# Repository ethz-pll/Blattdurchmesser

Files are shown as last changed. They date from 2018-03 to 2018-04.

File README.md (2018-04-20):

<!--
docu: [![doxygen html](https://raw.githubusercontent.com/ethz-pll/Blattdurchmesser/result/docu/doc/html/doxygen.png)](https://rawgit.com/ethz-pll/Blattdurchmesser/result/docu/doc/html/index.html)

[comment]: # (doxygen latex pdf output? https://github.com/drtrigon/sketchbook/blob/result/docu/doc/latex/refman.pdf)

code: [![Build Status](https://travis-ci.org/ethz-pll/Blattdurchmesser.svg?branch=master)](https://travis-ci.org/ethz-pll/Blattdurchmesser)

PCB: [![design rule check status](https://edrc.me/api/v1/user/drtrigon/project/ethz-pll-eagle/img/status.svg)](https://edrc.me/g/drtrigon/ethz-pll-eagle)
[![GERBER Build Status](https://travis-ci.org/drtrigon/ethz-pll-eagle.svg?branch=master)](https://travis-ci.org/drtrigon/ethz-pll-eagle)
https://gitlab.ethz.ch/PLL/eagle

[![projects/Blattdurchmesser/Blattdurchmesser_sch.png](https://raw.githubusercontent.com/drtrigon/ethz-pll-eagle/result/pcb/projects/Blattdurchmesser/Blattdurchmesser_sch.png)](https://github.com/drtrigon/ethz-pll-eagle/blob/result/pcb/projects/Blattdurchmesser/Blattdurchmesser_sch.png)

[![projects/Blattdurchmesser/Blattdurchmesser.brd from EDRC.me](https://edrc.me/api/v1/user/drtrigon/project/ethz-pll-eagle/img/file/projects%2FBlattdurchmesser%2FBlattdurchmesser.png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)](https://edrc.me/g/drtrigon/ethz-pll-eagle)
[![projects/Blattdurchmesser/Blattdurchmesser.png](https://raw.githubusercontent.com/drtrigon/ethz-pll-eagle/result/pcb/projects/Blattdurchmesser/Blattdurchmesser.png)](https://github.com/drtrigon/ethz-pll-eagle/blob/result/pcb/projects/Blattdurchmesser/Blattdurchmesser.png)
* GERBER: https://github.com/drtrigon/ethz-pll-eagle/blob/result/pcb/projects/Blattdurchmesser/Blattdurchmesser.zip
* partlist: https://github.com/drtrigon/ethz-pll-eagle/blob/result/pcb/projects/Blattdurchmesser/Blattdurchmesser.txt

https://github.com/drtrigon/ethz-pll-eagle/tree/result/pcb/projects/Blattdurchmesser logs:
* https://github.com/drtrigon/ethz-pll-eagle/blob/result/pcb/projects/Blattdurchmesser/Blattdurchmesser.gpi
* https://github.com/drtrigon/ethz-pll-eagle/blob/result/pcb/projects/Blattdurchmesser/Blattdurchmesser.dri

[![projects/Blattdurchmesser/Blattdurchmesser_auto.png](https://raw.githubusercontent.com/drtrigon/ethz-pll-eagle/result/pcb/projects/Blattdurchmesser/Blattdurchmesser_auto.png)](https://github.com/drtrigon/ethz-pll-eagle/blob/result/pcb/projects/Blattdurchmesser/Blattdurchmesser_auto.png)
-->
docu: doxygen html[...](https://rawgit.com/ethz-pll/Blattdurchmesser/result/docu/doc/html/index.html)

[comment]: # (doxygen latex pdf output? https://github.com/drtrigon/sketchbook/blob/result/docu/doc/latex/refman.pdf)

code: [...](https://travis-ci.org/ethz-pll/Blattdurchmesser)

PCB: design rule check status[...](https://edrc.me/g/drtrigon/ethz-pll-eagle)
[...](https://travis-ci.org/drtrigon/ethz-pll-eagle)
https://gitlab.ethz.ch/PLL/eagle


[...](https://github.com/drtrigon/ethz-pll-eagle/blob/result/pcb/projects/Blattdurchmesser/Blattdurchmesser_sch.png)

projects/Blattdurchmesser/Blattdurchmesser.brd from EDRC.me[...](https://edrc.me/g/drtrigon/ethz-pll-eagle)

[...](https://github.com/drtrigon/ethz-pll-eagle/blob/result/pcb/projects/Blattdurchmesser/Blattdurchmesser.png)
* GERBER: https://github.com/drtrigon/ethz-pll-eagle/blob/result/pcb/projects/Blattdurchmesser/Blattdurchmesser.zip
* partlist: https://github.com/drtrigon/ethz-pll-eagle/blob/result/pcb/projects/Blattdurchmesser/Blattdurchmesser.txt

https://github.com/drtrigon/ethz-pll-eagle/tree/result/pcb/projects/Blattdurchmesser logs:
* https://github.com/drtrigon/ethz-pll-eagle/blob/result/pcb/projects/Blattdurchmesser/Blattdurchmesser.gpi
* https://github.com/drtrigon/ethz-pll-eagle/blob/result/pcb/projects/Blattdurchmesser/Blattdurchmesser.dri


[...](https://github.com/drtrigon/ethz-pll-eagle/blob/result/pcb/projects/Blattdurchmesser/Blattdurchmesser_auto.png)

CAD: 
* https://gitlab.ethz.ch/PLL/Blattdurchmesser/blob/master/Catia/40%20mm%20Aluprofil%20v13.stl
  ([github](https://github.com/ethz-pll/Blattdurchmesser/blob/master/Catia/40%20mm%20Aluprofil%20v13.stl))
* https://gitlab.ethz.ch/PLL/Blattdurchmesser/blob/master/Catia/Saegeblatt_Anschlag.stl
  ([github](https://github.com/ethz-pll/Blattdurchmesser/blob/master/Catia/Saegeblatt_Anschlag.stl))
* https://gitlab.ethz.ch/PLL/Blattdurchmesser/blob/master/Catia/Saegeblatt_Endplatte.stl
  ([github](https://github.com/ethz-pll/Blattdurchmesser/blob/master/Catia/Saegeblatt_Endplatte.stl))
* https://gitlab.ethz.ch/PLL/Blattdurchmesser/blob/master/Catia/Saegeblatt_Schlitten.stl
  ([github](https://github.com/ethz-pll/Blattdurchmesser/blob/master/Catia/Saegeblatt_Schlitten.stl))

partlist: https://rawgit.com/ethz-pll/Blattdurchmesser/master/Materialliste.htm

[comment]: # (@htmlonly
    <table>
      <tr>
        <td>
          <script src="https://embed.github.com/view/3d/ethz-pll/Blattdurchmesser/master/Catia/40%20mm%20Aluprofil%20v13.stl"></script><br>
          <script src="https://embed.github.com/view/3d/ethz-pll/Blattdurchmesser/master/Catia/Saegeblatt_Anschlag.stl"></script><br>
          <script src="https://embed.github.com/view/3d/ethz-pll/Blattdurchmesser/master/Catia/Saegeblatt_Endplatte.stl"></script><br>
          <script src="https://embed.github.com/view/3d/ethz-pll/Blattdurchmesser/master/Catia/Saegeblatt_Schlitten.stl"></script><br>
        </td>
      </tr>
    </table>
@endhtmlonly)

#### changelog pcb (eagle)

todo 1.0 -> 1.1

* ...

main changes 1.0 -> 1.1

* ...

## Setup

I would like to use features like CI (continous integration) keep a copy/mirror on e.g. github and more.

ETHZ GitLab could (and may be already does) support such features but I do not understand how this works.

Maintaining a copy/mirror (more precise: with 2 remotes overloaded origin) on GitHub also allows
to use GitLab and GitHub together and by that all the nice featurs on GitHub.
See also; https://steveperkins.com/migrating-projects-from-github-to-gitlab/

"Option 2: Overload Origin with Both Remotes (needs one single pull/push only)"; in order to clone
and set this repo up use:
```
$ git clone https://gitlab.ethz.ch/PLL/Blattdurchmesser.git
$ cd Blattdurchmesser
$ git remote set-url --add origin https://github.com/ethz-pll/Blattdurchmesser.git
```
you can check the settings with:
```
$ git remote -v
origin  https://gitlab.ethz.ch/PLL/Blattdurchmesser.git (fetch)
origin  https://gitlab.ethz.ch/PLL/Blattdurchmesser.git (push)
origin  https://github.com/ethz-pll/Blattdurchmesser.git (push)
```

### Enable Travis CI for a Repository (for Arduino)
https://learn.adafruit.com/continuous-integration-arduino-and-you/testing-your-project

Login to Travis-CI using the GitHub account and enable Travis-CI for the given repo.

Add a .travis.yml file to your project, commit, pull/push and enjoy.

### Enable EDRC.ME for a Repository (for Eagle)
See https://gitlab.ethz.ch/PLL/eagle

### Enable CAD View (for Catia)
* https://help.github.com/articles/3d-file-viewer/
* https://blog.github.com/2013-04-09-stl-file-viewing/
* https://blog.github.com/2013-09-17-3d-file-diffs/

#### Create CAD (.stl) Designs online easily
See https://www.tinkercad.com/

### Further Info
* convert STEP file to .stl online: https://www.makexyz.com/convert/step-to-stl
* convert Catia file to .stl online: https://www.convertcadfiles.com/de/konvertieren/
* add doxygen to repository
  * The Well-Automated Arduino Library - Adafruit Learning System: https://learn.adafruit.com/the-well-automated-arduino-library/doxygen
  * https://stackoverflow.com/questions/35500277/doxygen-for-ino-files-arduino

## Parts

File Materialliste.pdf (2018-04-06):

Bezeichnung | Laden | Art.-Nr. | Preis | Anzahl
Original Arduino Uno R3 (Atmega328) *RETAIL* | www.play-zone.ch | | 28.90 | 1
A4988 Stepper Driver Modul | www.play-zone.ch | 8.90 | 1 bei www.distrelec.ch CHF 30.35 / bei www.3dware.ch CHF 4.20
OLED Modul 128 x 64 Pixel, I2C, Weiss, 0.96 inch, SSD1306 | www.play-zone.ch | | 14.90 | 1 | welcher? SSD1306 oder …
OLED Modul 1.3" / 128 x 64 Pixel, I2C, Weiss, SH1106 | www.play-zone.ch | | 18.90 | 1 | … SH1106? welchen habe ich hier? Siehe auch https://forum.arduino.cc/index.php?topic=256374.0
Stepper Motor, 200 step, DC 8.64V, 0.24A | FIRST-Lab | (ca. 25.00) | 1 Betrieben mit 12V (mehr Drehmoment, weniger blockieren) - Kühlung??
Profil-System (Item, Kanya, etc.) Profil 40 x 40 x 100 mm | FIRST-Lab | 1 Was für System haben wir verwendet?
Verbindung Stepper Motor zu Profil-System, blau, H.J. Rusterholz | FIRST-Lab | 3D-Druck | | 1
Spindel M5 x 100mm, 0.8mm/Umdrehung | FIRST-Lab | | | 1
Bronze-Buchse M5 | FIRST-Lab | | | 1
Leuchtenklemmen, 6mm2 | lager.phys.ethz.ch | 30067.6 | 1.79 | 1 | welche Kupplung?
Stellringe, 3, 7, M2 | lager.phys.ethz.ch | 20247.2 | 0.43 | 2 | welche Kupplung?
PVC-Schläuche, 2, 4 | lager.phys.ethz.ch | 40001.1 | 0.37 | 15 mm | welche Kupplung?
Kühlkörper, Typ FK 214/SA CB, 15 K/W | lager.phys.ethz.ch | 30049.4 | 0.64 | 3
Kupplungen/Klaue/Nabenklemmung mit Passfedernut: https://de.misumi-ec.com/vona2/detail/110300125940/ | welche Kupplung?
Wellenkupplung: http://forums.reprap.org/read.php?246,280197
Kardan: https://de.aliexpress.com/item/5pcs-Cross-universal-joint-drive-shaft-axle-coupling-metal-connector-diy-toy-accessories-technology-model-parts/32827812832.html Drehstarre Kupplung: http://shop.myhobby-cnc.de/bauteile/mechanische-bauteile/kleinteile/21/drehstarre-kupplung
ROTEX Kupplung KTR Rotex 28: http://www.maschinenteil24.de/Mechanik/Mechanische-Baugruppen/Kupplungen/Kupplung-KTR-Rotex-28.html
Kardan: https://de.aliexpress.com/item/5pcs-Cross-universal-joint-drive-shaft-axle-coupling-metal-connector-diy-toy-accessories-technology-model-parts/32827812832.html Starre Kupplungen: http://www.directindustry.de/industrie-hersteller/starre-kupplung-61105.html
Vermeidung von Kupplungsausfällen: http://deutsch.ruland.com/a_articles_avoid_coup_failure_de.asp
Gabellichtschranke, PM-T64, Panasonic | www.distrelec.ch | 300-38-924 | 18.36 | 1
Konfektioniertes Kabel, 2 m, 3.7 mm, 0.2 mm² 4-Core, CN-14A-C2, Panasonic | www.distrelec.ch | 300-38-891 | 8.37 | 1
Relais, TX2-5V, Panasonic | www.distrelec.ch | 137-10-935 | 3.51 | 1
Miniatur-Mikroschalter, mit Hebel | lager.phys.ethz.ch | 30167.2 | 8.74
Schlitten PTFE: "Catia\Saegeblatt_Schlitten.pdf" | (Lehr-)Werkstatt | | | 1
Anschlag Al: "Catia\Saegeblatt_Anschlag.pdf" | (Lehr-)Werkstatt | | | 1 | besser SS? wegen Verschleiss…?
Endplatte Al: "Catia\Saegeblatt_Endplatte.pdf" | (Lehr-)Werkstatt | | | 1

Kostenstelle ist 2205, Vermerk "Wafersäge"

bei www.distrelec.ch CHF 30.35 / bei www.3dware.ch CHF 4.20
welcher? SSD1306 oder …
… SH1106? welchen habe ich hier? Siehe auch https://forum.arduino.cc/index.php?topic=256374.0

Betrieben mit 12V (mehr Drehmoment, weniger blockieren) - Kühlung??
Was für System haben wir verwendet?

welche Kupplung?
welche Kupplung?
welche Kupplung?

welche Kupplung?

besser SS? wegen Verschleiss…?

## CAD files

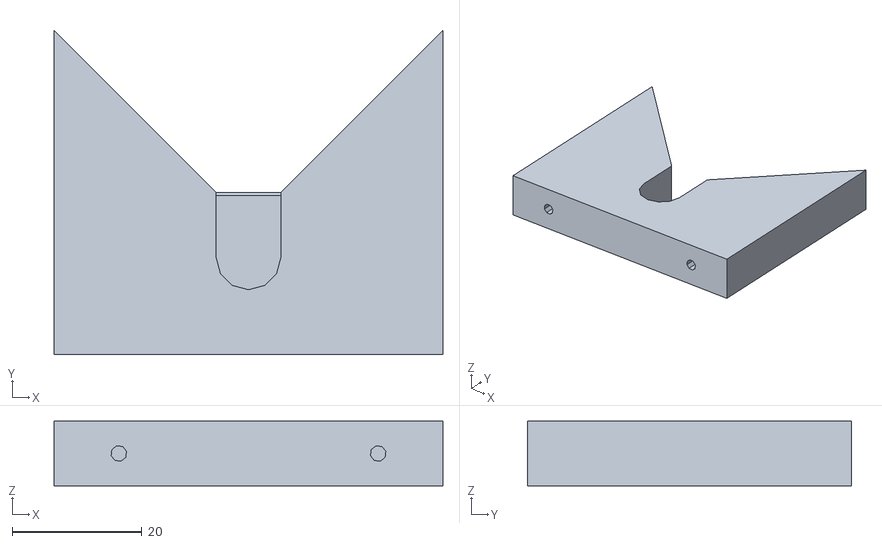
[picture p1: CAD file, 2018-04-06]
Catia/Saegeblatt_Anschlag.stl
60.0 x 50.0 x 10.0

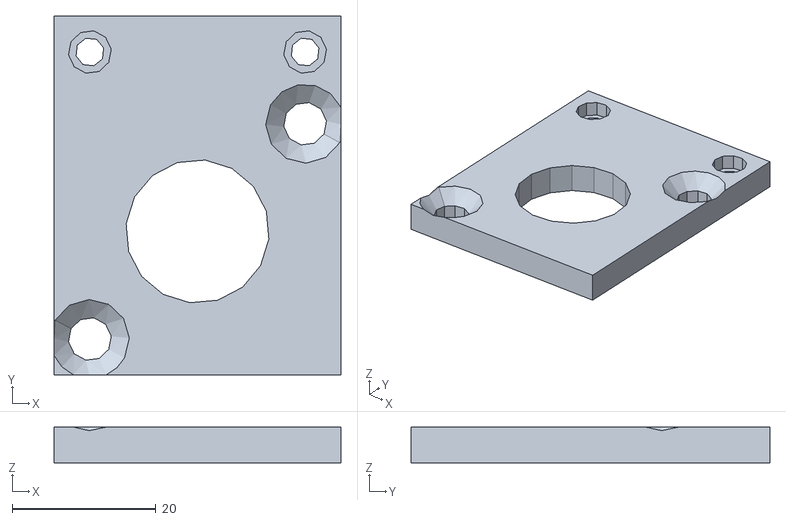
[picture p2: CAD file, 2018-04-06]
Catia/Saegeblatt_Endplatte.stl
40.0 x 50.0 x 5.00

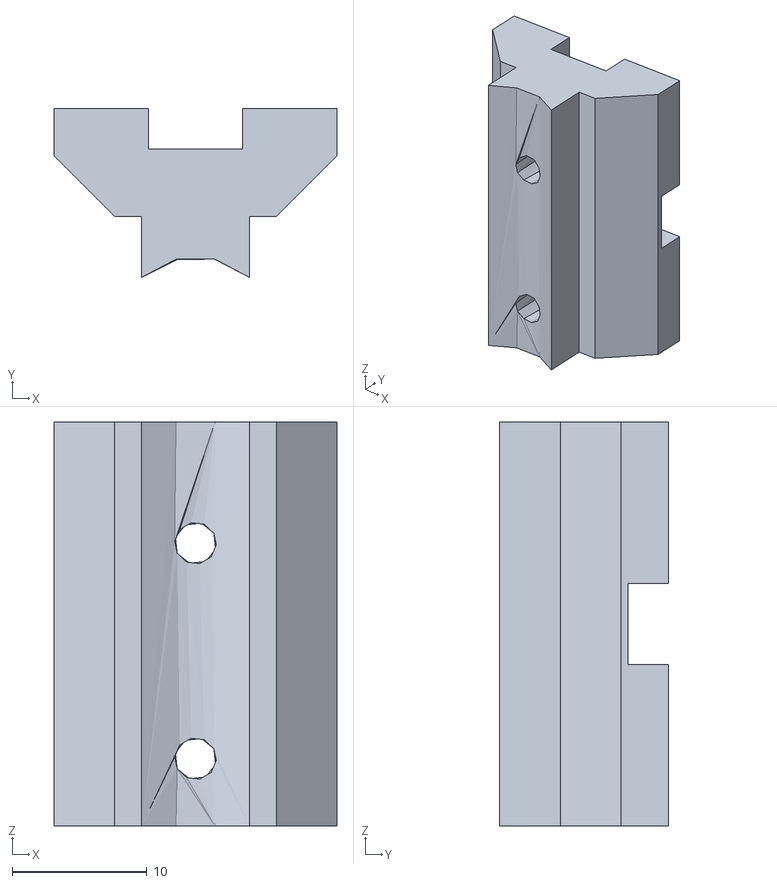
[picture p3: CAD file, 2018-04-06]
Catia/Saegeblatt_Schlitten.stl
21.0 x 12.5 x 30.0

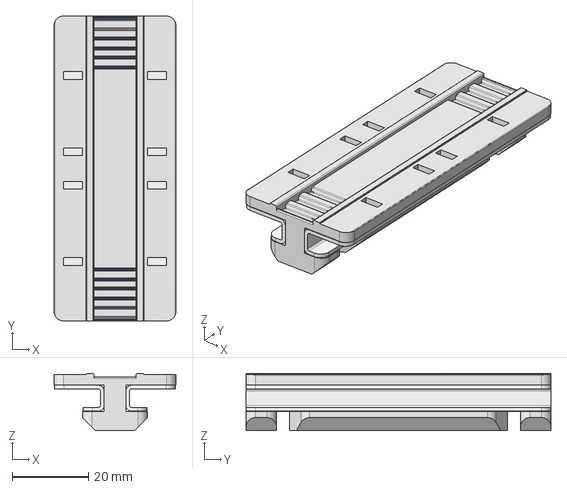
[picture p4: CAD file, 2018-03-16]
Catia/item_0060739_Gleitschlitten_F_hrung_8_80x40_4.stp
32.0 x 80.0 x 15.0 mm

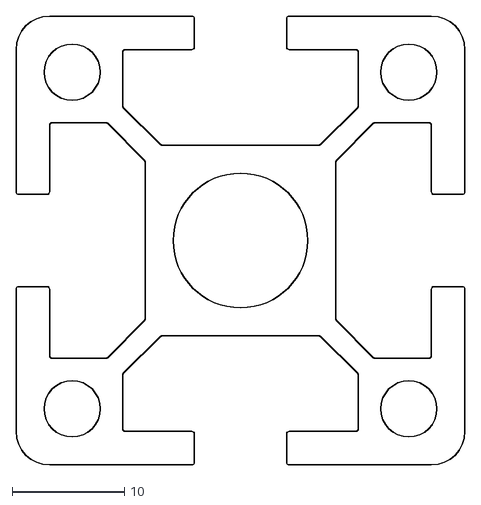
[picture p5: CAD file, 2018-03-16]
Catia/40mm Aluprofil.dxf
40.0 x 40.0

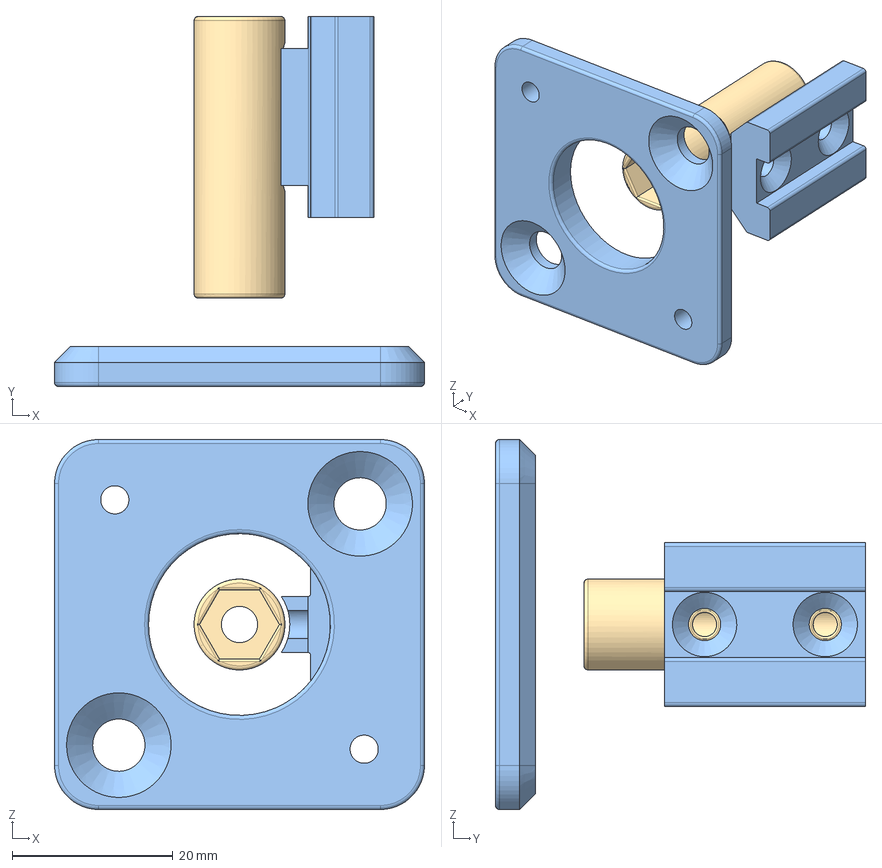
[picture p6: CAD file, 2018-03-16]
Catia/40 mm Aluprofil v13.step
46.0 x 46.0 x 46.0 mm

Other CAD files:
Catia/40 mm Aluprofil v13.f3d
Catia/40 mm Aluprofil v13.iges
Catia/40 mm Aluprofil v13.stl
Catia/Saegeblatt_Anschlag.CATPart
Catia/Saegeblatt_Endplatte.CATPart
Catia/Saegeblatt_Schlitten.CATPart

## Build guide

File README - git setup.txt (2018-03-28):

I would like to use features like CI (continous integration) keep a copy/mirror on e.g. github and more.

ETHZ GitLab could (and may be already does) support such features but I do not understand how this works.

Maintaining a copy/mirror (more precise: with 2 remotes overloaded origin) on GitHub also allows
to use GitLab and GitHub together and by that all the nice featurs on GitHub.
https://steveperkins.com/migrating-projects-from-github-to-gitlab/

Option 2: Overload Origin with Both Remotes (needs one single pull/push only);
$ git remote set-url --add origin https://github.com/drtrigon/ethz-pll-Blattdurchmesser.git

https://gitlab.ethz.ch/PLL/Blattdurchmesser
https://github.com/drtrigon/ethz-pll-Blattdurchmesser

Enable Travis CI for a Repository (for Arduino)
https://learn.adafruit.com/continuous-integration-arduino-and-you/testing-your-project

Login to Travis-CI using the GitHub account and enable Travis-CI for the given repo.

Add a .travis.yml file to your project, commit, pull/push and enjoy.

This travis file supports Arduino IDE 1.6.5 only we use 1.8.2.

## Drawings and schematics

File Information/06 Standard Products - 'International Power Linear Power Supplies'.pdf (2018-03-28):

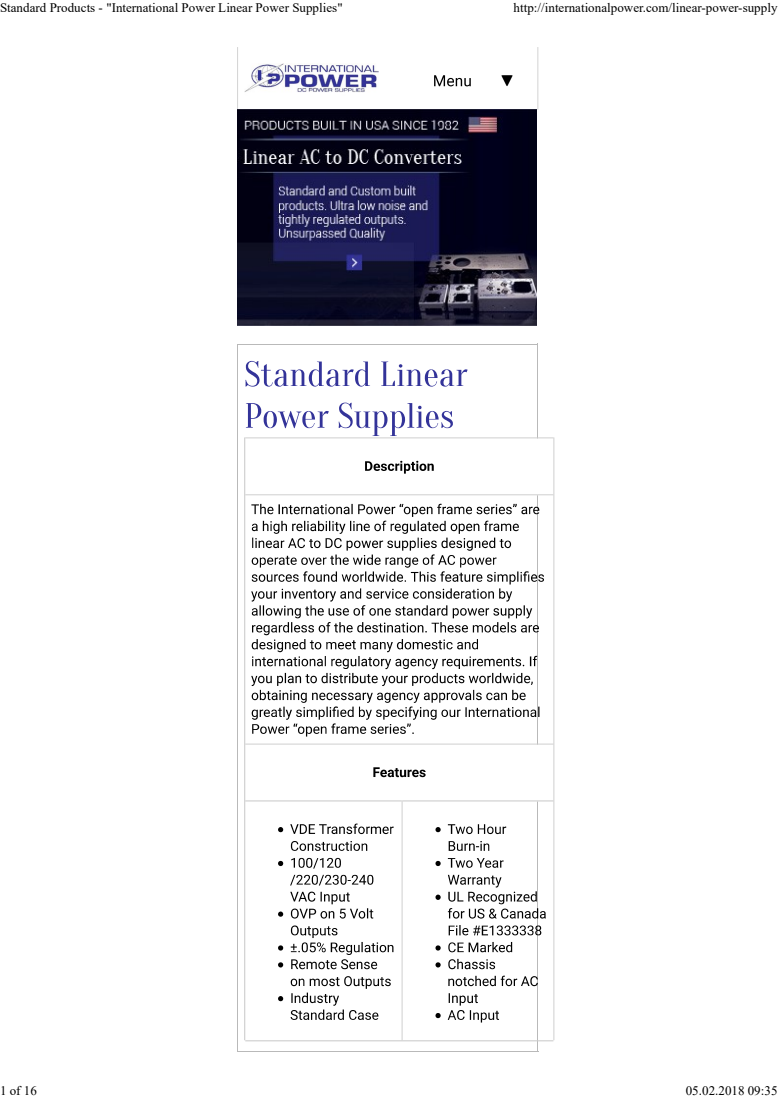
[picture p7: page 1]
Standard Products - "International Power Linear Power Supplies"; http://internationalpower.com/linear-power-supply

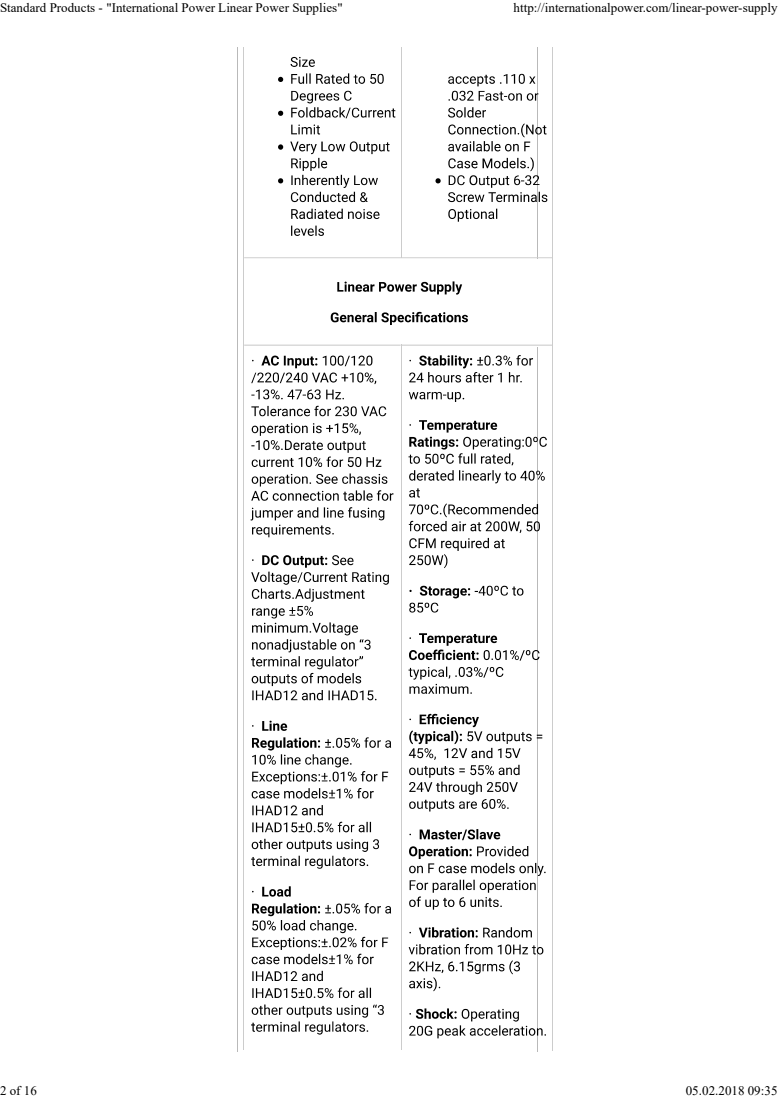
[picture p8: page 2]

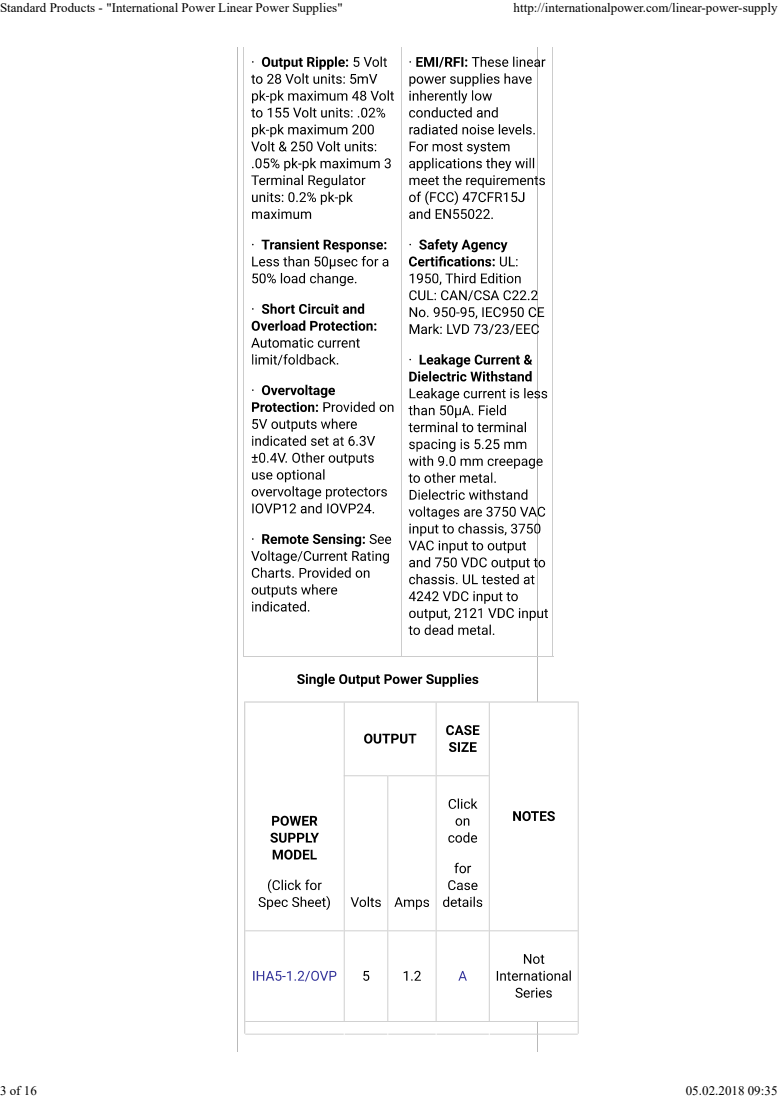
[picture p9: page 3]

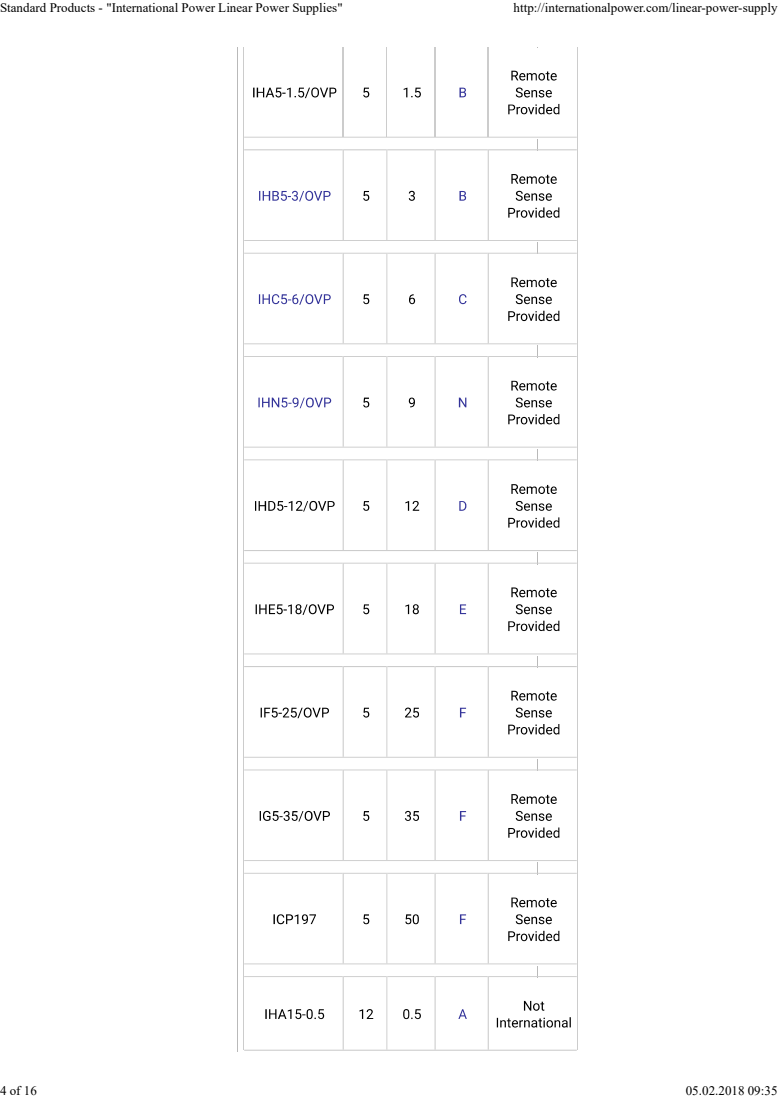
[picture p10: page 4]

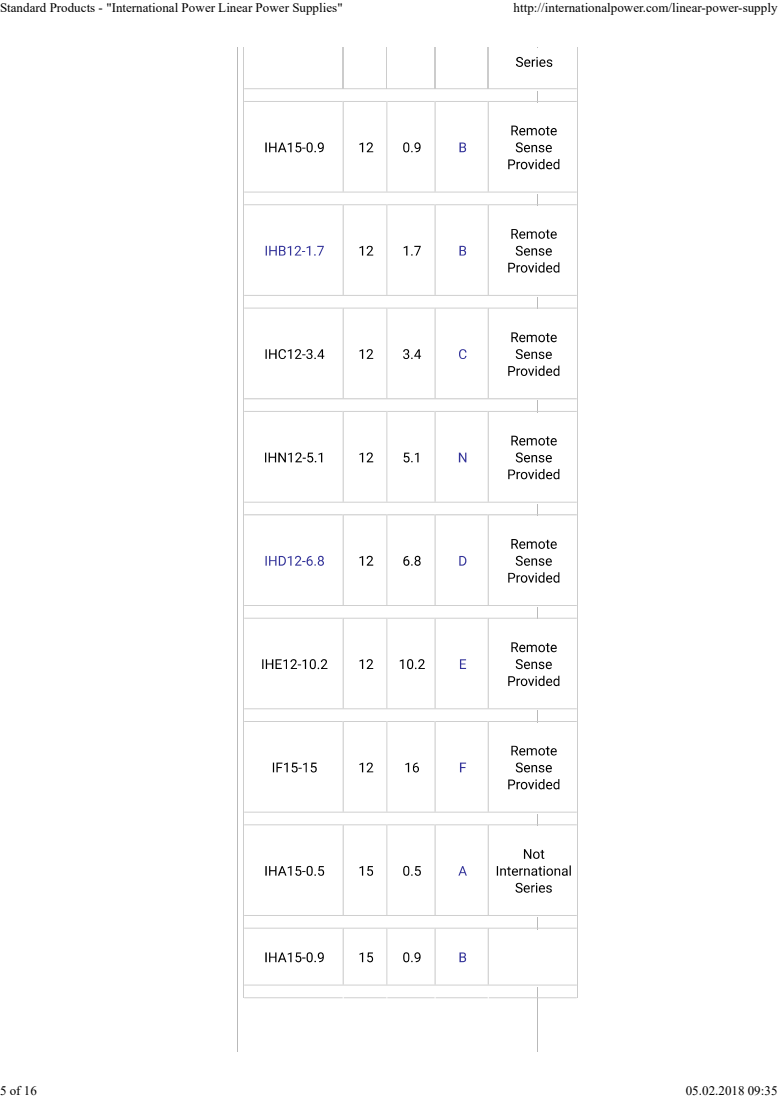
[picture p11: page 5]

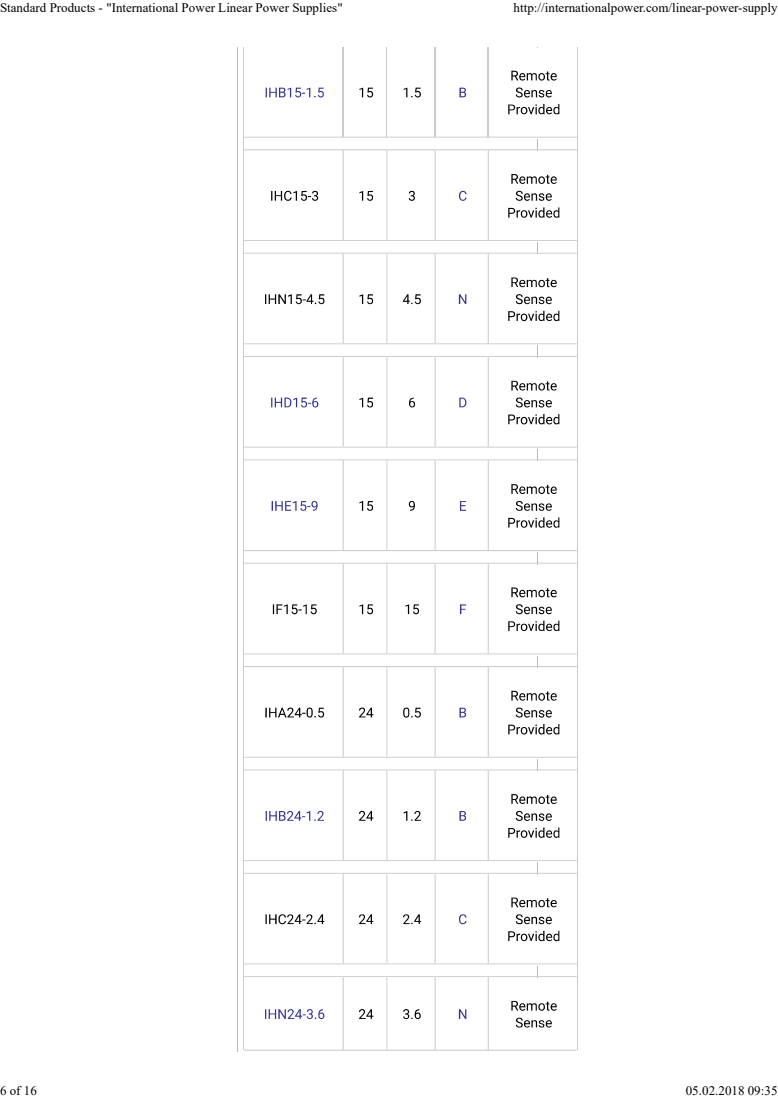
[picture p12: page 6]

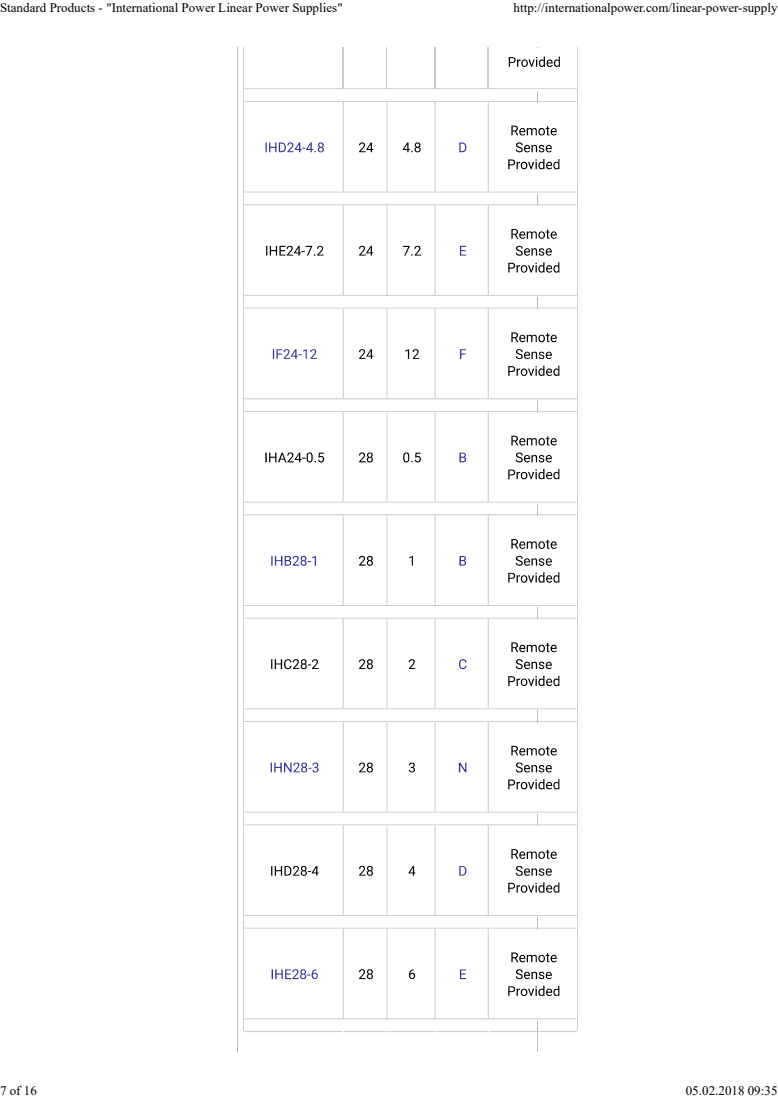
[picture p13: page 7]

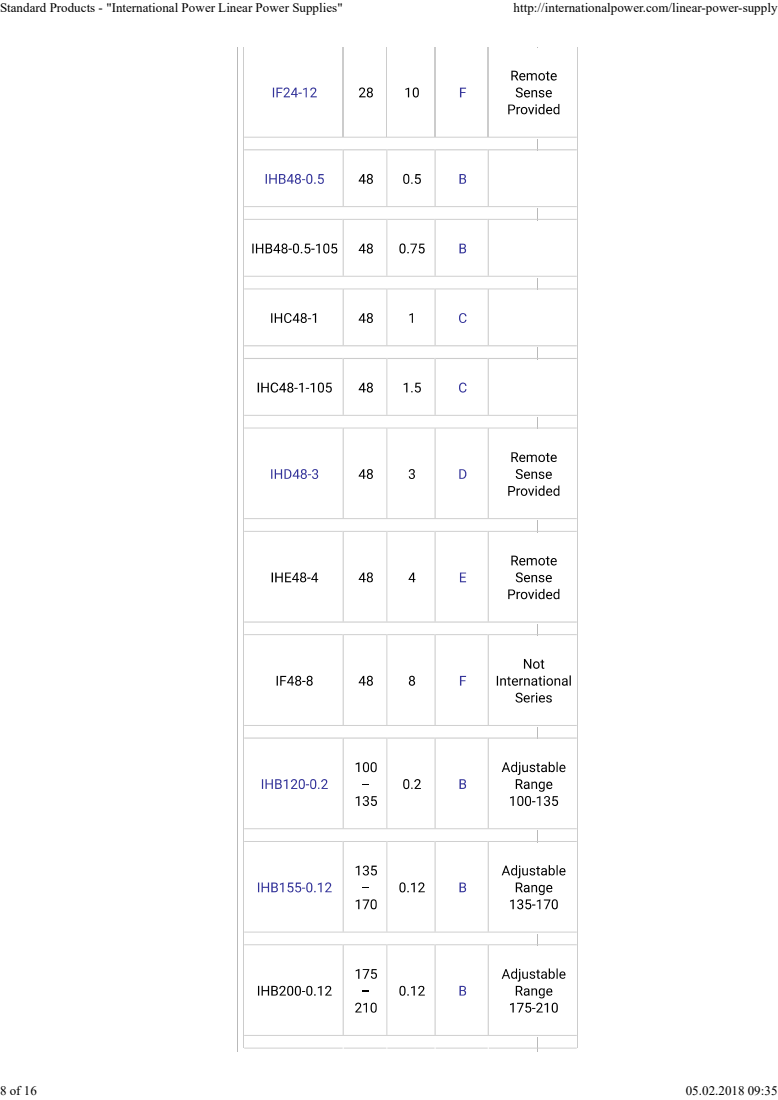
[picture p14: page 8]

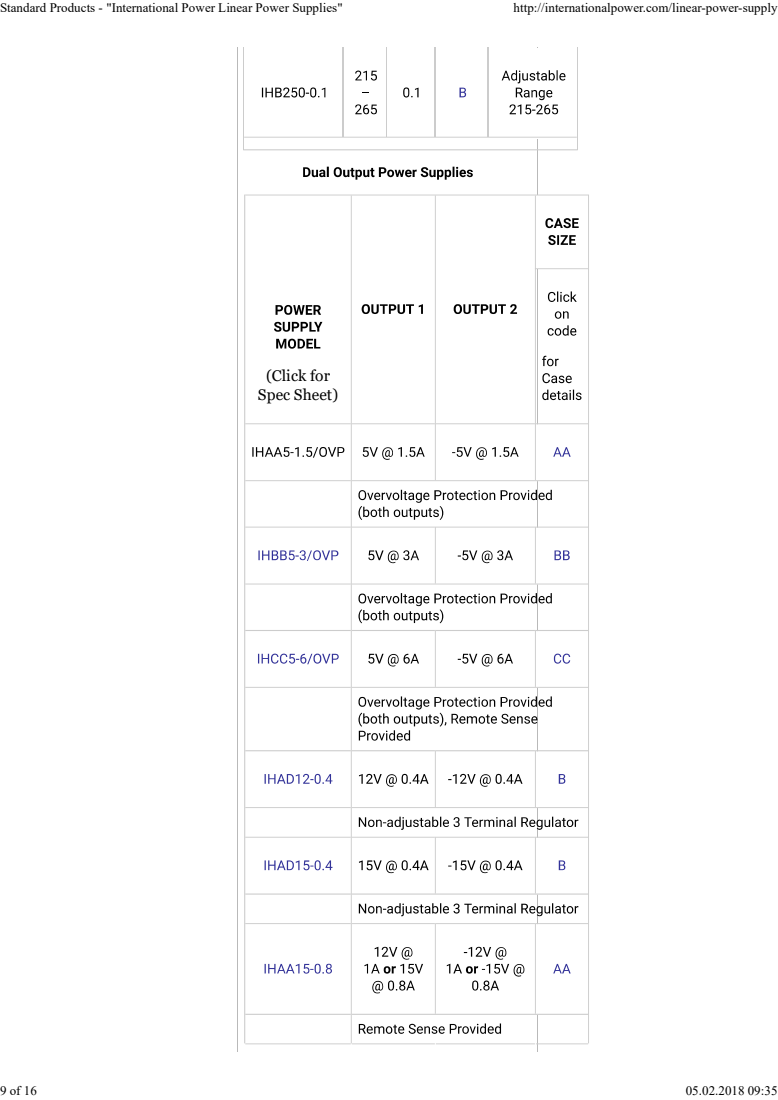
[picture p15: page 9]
(Click for Spec Sheet)

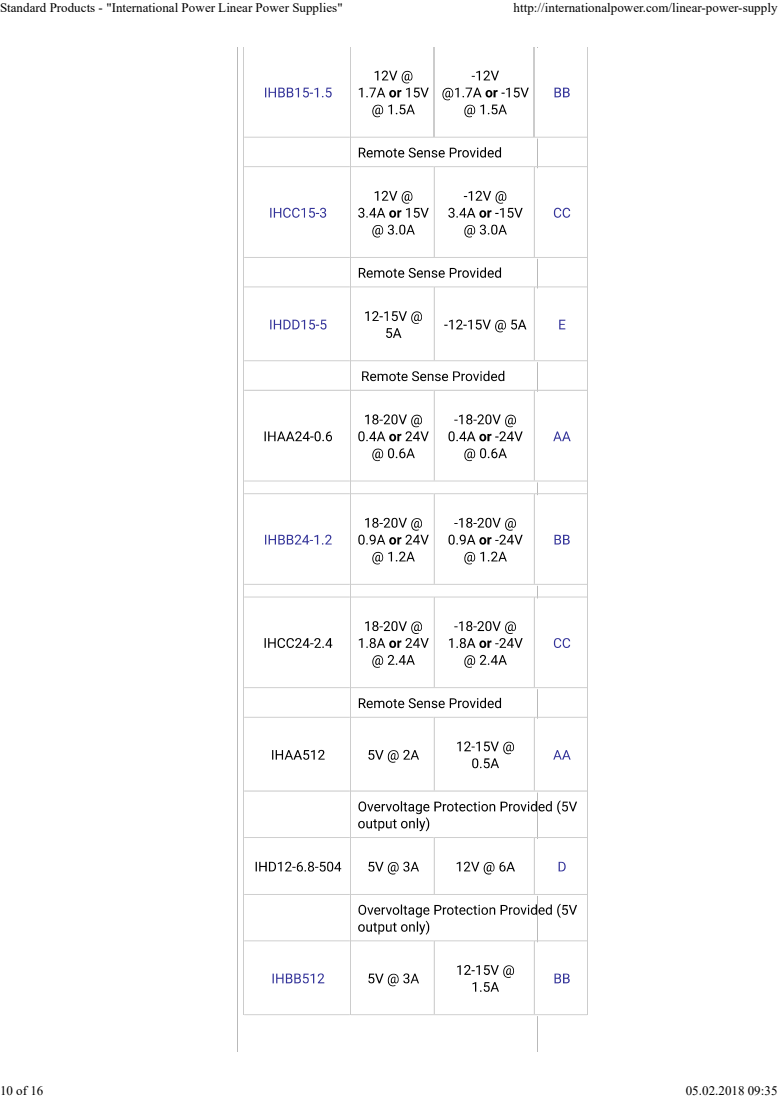
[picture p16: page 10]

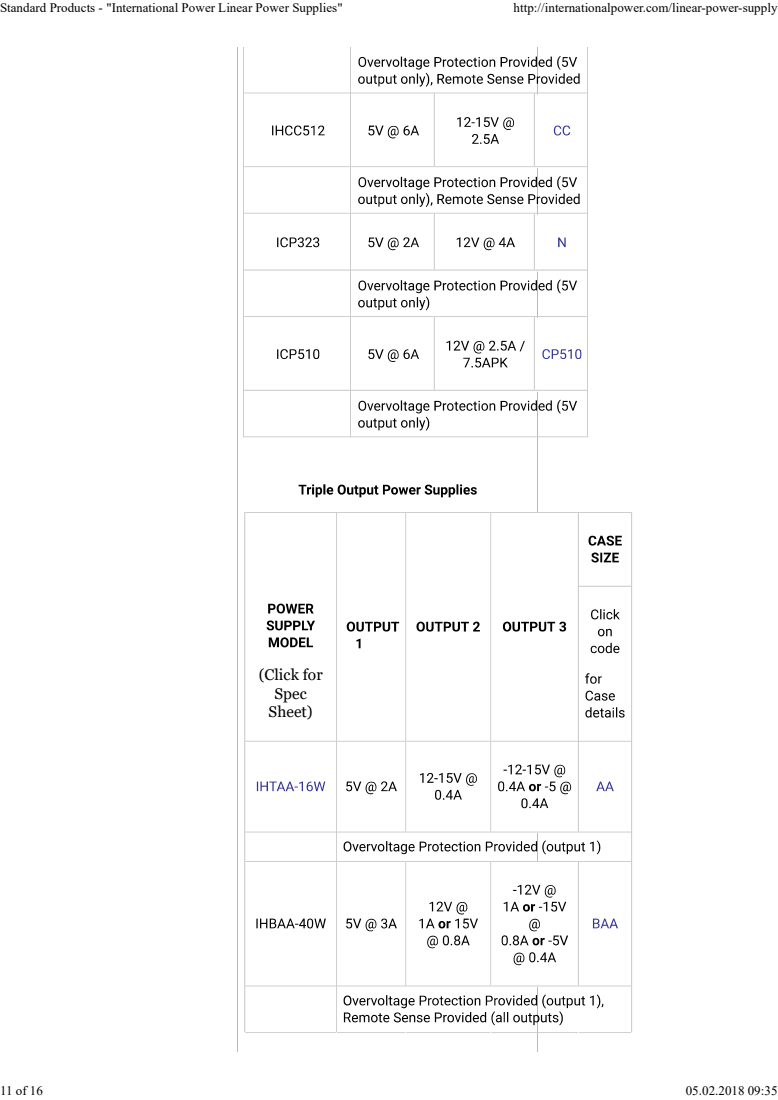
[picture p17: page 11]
(Click for Spec Sheet)

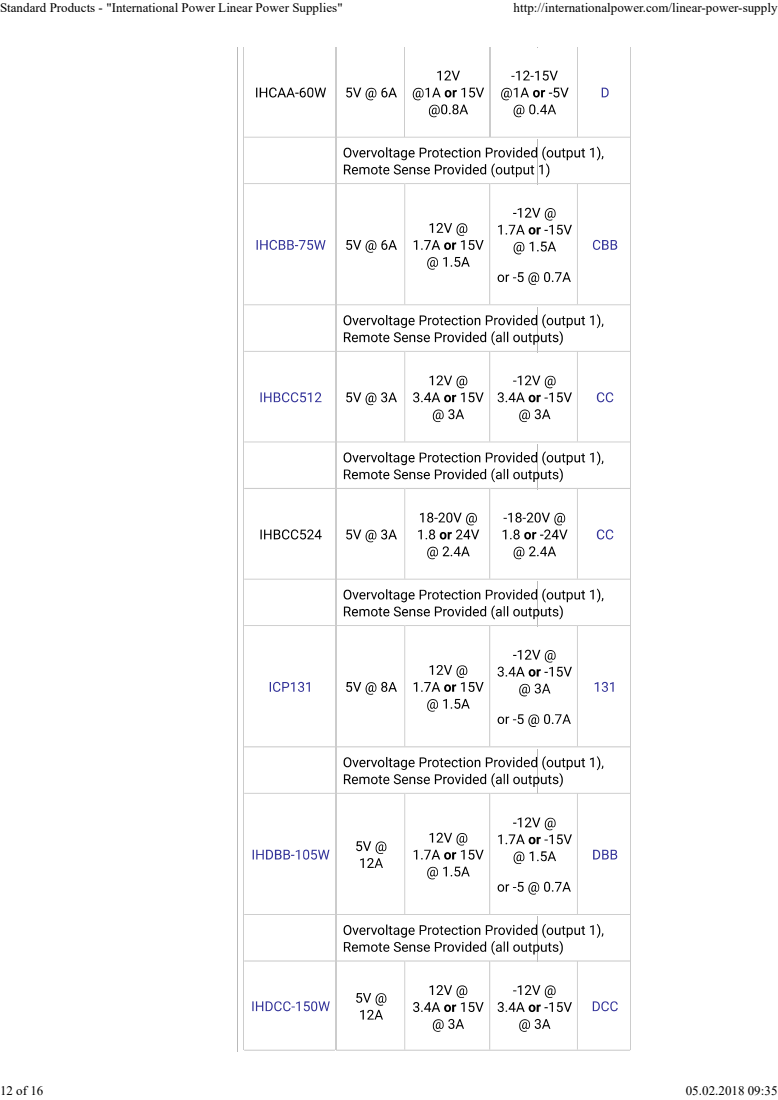
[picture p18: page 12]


* Overvoltage Protection Provided ‡
Remote Sense Provided




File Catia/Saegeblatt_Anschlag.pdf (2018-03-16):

Maßstab: 1:1; Detail A; Maßstab: 4:10.5 x 45°

beidseitig (oben und unten)

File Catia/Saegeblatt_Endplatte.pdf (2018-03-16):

Maßstab: 1:1

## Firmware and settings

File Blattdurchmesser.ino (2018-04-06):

/*     Simple Stepper Motor Control Exaple Code
 *
 *  by Dejan Nedelkovski, www.HowToMechatronics.com
 *  http://howtomechatronics.com/tutorials/arduino/how-to-control-stepper-motor-with-a4988-driver-and-arduino/
 *
 *  stepper: 360 deg by 200 steps -> 1.8 deg per step
 *  screw: 8 mm on 10 turns -> 0.8 mm per turn
 *  -> 0.8/200 = 0.004 mm by step
 *
 *  Test show typical accuracy with PM-64 is <= 50um per try.
 *
 * !!! Ablauf: siehe Flussdiagramm Hansjakob !!!
 * !!! Kupplung Spindel - Motor: flexible Kupplung !!!
 *
 * FreeRTOS + stepper motor:
 * - see "Example 6. Combining blocking and non-blocking tasks"
 *   https://www.freertos.org/Documentation/161204_Mastering_the_FreeRTOS_Real_Time_Kernel-A_Hands-On_Tutorial_Guide.pdf
 *
 * Stepper libs:
 * - need; A4988 support, exact step-by-step move, position, non-blocking (FreeRTOS)
 * - nice to have: acceleration
 * - look at https://www.arduino.cc/en/Reference/Stepper (speed, single step - but blocking)
 *           https://github.com/laurb9/StepperDriver (speed, single step, non-blocking)
 *           File > Examples > StepperDriver > BasicStepperDriver also NonBlocking
 *           https://github.com/waspinator/AccelStepper
 * - if not available write own or enhance given one
 *
 * OLED lib:
 * - SSD1306 only: https://github.com/greiman/SSD1306Ascii
 * - SSD1306, SH1106: https://github.com/stanleyhuangyc/MultiLCD
 * - look at https://forum.arduino.cc/index.php?topic=256374.0
 *
 * PCB:
 * - Arduino UNO eagle footprint
 *   https://github.com/adafruit/Adafruit-Eagle-Library
 *
 */

#define SERIAL_OUTPUT  // enable verbose serial output

/*
#define MOTOR_DIR   6
#define MOTOR_STEP  7
#define MOTOR_ENA   8
#define optoPin     A0   // may be use both digital and analog pin (for int.)
#define swchPin     9
// OLED on I2C pins SCL, SDA
*/
#define TOL_LOW       -1  // < 0.5 mm tolerance ...
#define TOL_HIGH      -1  //
#define START_BUTTON  -1

// defines pins numbers
#define stepPin    3  // stepper motor control STEP
#define dirPin     4  // stepper motor control DIR

#define optoPinA   8  // optical sensor reading (int possible?)
#define optoPinB   2  // optical sensor reading (int possible)
#define swchPinA   9  // mechanical sensor reading (int possible?)
#define swchPinB  10  // mechanical sensor reading (int possible?)

#define distpstp 0.004  // 0.004 mm per step

//------------------------------------------------------------------------------

#include <Wire.h>
#include "SSD1306Ascii.h"
#include "SSD1306AsciiWire.h"

// 0X3C+SA0 - 0x3C or 0x3D
#define I2C_ADDRESS 0x3C

SSD1306AsciiWire oled;

//------------------------------------------------------------------------------

void setup() {
  // Init/Setup
  // Configure serial interface
#ifdef SERIAL_OUTPUT
  Serial.begin(9600);

  // http://www.instructables.com/id/Arduino-Lesser-Known-Features/
  Serial.println("SOFTWARE:");
  Serial.println(__DATE__); // compilation date
  Serial.println(__TIME__); // compilation time
  String stringOne = String(ARDUINO, DEC);
  Serial.println(stringOne); // arduino ide version
  Serial.println(__VERSION__); // gcc version
  Serial.println(__FILE__); // file compiled
#endif

  // Configure wire (i2c) and oled interfaces
  Wire.begin();
  Wire.setClock(400000L);

  oled.begin(&Adafruit128x64, I2C_ADDRESS);
  oled.setFont(System5x7);
  oled.clear();
//  oled.set2X();
//  oled.set1X();
  oled.println("\"Blattdurchmesser\"");

  // Define/Configure pins as input, output, etc.
  pinMode(stepPin, OUTPUT);
  pinMode(dirPin, OUTPUT);
  pinMode(optoPinA, INPUT_PULLUP);  // pull-up to allow check for sensor existence
  pinMode(optoPinB, INPUT_PULLUP);  // pull-up to allow check for sensor existence
  //pinMode(optoPinB, INPUT);        // use as interrupt?
  pinMode(swchPinA, INPUT_PULLUP);  // pull-up to allow check for sensor existence
  pinMode(swchPinB, INPUT_PULLUP);  // pull-up to allow check for sensor existence
  pinMode(LED_BUILTIN, OUTPUT);

  // System Self-Test
  bool selftest = true;
  selftest = selftest && (digitalRead(optoPinA)
                      && (!digitalRead(optoPinB)));  // test is optical sensor powered/connected and free?
//  selftest = selftest && ((digitalRead(optoPinA) == HIGH)
//                      && (digitalRead(optoPinB) == LOW));  // test is optical sensor powered/connected and free?
  if (!selftest) {
    oled.println("E: opt sw");
  }
  selftest = selftest && (digitalRead(swchPinA)
                      && (!digitalRead(swchPinB)));  // test is mechanical sensor powered/connected and free?
//  selftest = selftest && ((digitalRead(swchPinA) == HIGH)
//                      && (digitalRead(swchPinB) == LOW));  // test is mechanical sensor powered/connected and free?
  if (!selftest) {
    oled.println("E: mech sw");
  }
// test is stepper powered?
// test is stepper functional?
#ifdef SERIAL_OUTPUT
  Serial.println("RUN:");
#endif
  oled.println("RUN:");
#ifdef SERIAL_OUTPUT
  Serial.print("System Self-Test: ");
#endif
  oled.print("System Self-Test: ");
#ifdef SERIAL_OUTPUT
  Serial.println(selftest);
#endif
  oled.println(selftest);

  // Check current status and decide what to do as next step
  // - ...
  if (selftest) {  // System Init, Self-Test and ... SUCCESSFUL
    // blink 3 times
    digitalWrite(LED_BUILTIN, HIGH);  // LED on
    delay(500);
    digitalWrite(LED_BUILTIN, LOW);   // LED off
    delay(500);
    digitalWrite(LED_BUILTIN, HIGH);  // LED on
    delay(500);
    digitalWrite(LED_BUILTIN, LOW);   // LED off
    delay(500);
    digitalWrite(LED_BUILTIN, HIGH);  // LED on
    delay(500);
    digitalWrite(LED_BUILTIN, LOW);   // LED off

    oled.println("READY...");
  } else {         // System Init, Self-Test and ... FAILED
    digitalWrite(LED_BUILTIN, HIGH);  // LED on

    oled.println("ERROR: STOP!");
    while (true) {};  // loop for ever
  }

  delay(3000);

  oled.clear();
// TODO: check how much text fits on to the oled display (~12 chars per line?)
  oled.println("Remove dicing blade");
  oled.println("and press \"Start\"");
}

void loop() {
  measurement();

/*

  // if analog input pin 0 is unconnected, random analog
  // noise will cause the call to randomSeed() to generate
  // different seed numbers each time the sketch runs.
  // randomSeed() will then shuffle the random function.
  randomSeed(analogRead(0));

  Serial.begin(9600);
  // Sets the two pins as In-/Outputs
  pinMode(stepPin, OUTPUT); 
  pinMode(dirPin, OUTPUT);
  pinMode(optoPinB, INPUT);  // use as interrupt?
  pinMode(LED_BUILTIN, OUTPUT);

  digitalWrite(LED_BUILTIN, HIGH);

  digitalWrite(dirPin,HIGH); // BACK/UP; Enables the motor to move in a particular direction
//  digitalWrite(dirPin,LOW); // AWAY/DOWN; Enables the motor to move in a particular direction
//  const int turns =  random(1, 5);
  const int turns = 1;
  Serial.println(turns);
  Serial.println(turns * 200);
//  // Makes 200 pulses for making one full cycle rotation
//  for(int x = 0; x < (200 * turns); x++) {
  // Makes pulses for visibly moving the sledge in a direction
  for(int x = 0; x < (1000 * turns); x++) {
    digitalWrite(stepPin,HIGH); 
    delayMicroseconds(500); 
    digitalWrite(stepPin,LOW); 
    delayMicroseconds(500); 
  }
  delay(1000); // One second delay

/*
  digitalWrite(dirPin,LOW); //Changes the rotations direction
//  digitalWrite(dirPin,HIGH); // Enables the motor to move in a particular direction
  // Makes 400 pulses for making two full cycle rotation
  for(int x = 0; x < 4000; x++) {
    delay(2);  // sound becomes very unpleasant with higher values, but accuracy increases
    if(digitalRead(optoPinB) == HIGH) {
      Serial.println(x);
      Serial.println((turns * 200)-x);
      Serial.println(((turns * 200)-x)*0.004*1000);
      Serial.println("done");
      break;
    }
    digitalWrite(stepPin,HIGH);
    delayMicroseconds(500);
    digitalWrite(stepPin,LOW);
    delayMicroseconds(500);
  }


  digitalWrite(LED_BUILTIN, LOW);
*/
}

/*void loop() {
  digitalWrite(dirPin,HIGH); // Enables the motor to move in a particular direction
  // Makes 200 pulses for making one full cycle rotation
  for(int x = 0; x < 200; x++) {
    digitalWrite(stepPin,HIGH); 
    delayMicroseconds(500); 
    digitalWrite(stepPin,LOW); 
    delayMicroseconds(500); 
  }
  delay(1000); // One second delay
  
  digitalWrite(dirPin,LOW); //Changes the rotations direction
  // Makes 400 pulses for making two full cycle rotation
  for(int x = 0; x < 400; x++) {
    digitalWrite(stepPin,HIGH);
    delayMicroseconds(500);
    digitalWrite(stepPin,LOW);
    delayMicroseconds(500);
  }x/
  delay(1000);

  Serial.println(digitalRead(optoPinB));
  digitalWrite(LED_BUILTIN, !digitalRead(LED_BUILTIN));

}*/

void measurement() {
  init_measurement();
  while (!run_measurement()) {};
}

void init_measurement() {
  // wait for "Start" button (has pull-up on port)
// TODO: #define START_BUTTON
// TODO: add "Start" and "Reset" buttons
  while (digitalRead(START_BUTTON) == HIGH) {};

  oled.clear();
  oled.println("Init in Progress");
  oled.println("Please wait...");

return;

// TODO: Besprechen mit HJ; kann nach meiner init Prozedur gar nicht sein
//     + -> Fehler tritt davor auf in setup() bei Init auf
//   ! - -> kann NICHT selbst versuchen durch -Fahrt Fehler zu beheben
  if (digitalRead(swchPinB) == HIGH) {    // mech sw pressed?
    // move 5mm in -dir
    // ...
    if (digitalRead(swchPinB) == HIGH) {  // mech sw pressed?
      // ERROR: Axis blocked or reference switch defect!
      // Please restart machine or call for assistance!
      while (true) {};  // "Ende"; loop for ever
    }
  }

  // move to reference mech sw in +dir an store position
// TODO: Besprechen mit HJ; "Endschalter: Mechanischer Microswitch NO" -> "NO" ??
  // ...

// TODO: Besprechen mit HJ; kann nach meiner init Prozedur gar nicht sein
//     + -> Fehler tritt davor auf in setup() bei Init auf
//   ! - -> kann NICHT selbst versuchen durch -Fahrt Fehler zu beheben
// TODO: Besprechen mit HJ; STOP == Ende?
// TODO: Besprechen mit HJ; Wie kann Min/Max des optischen sensors gemessen werden?
// TODO: Consider using analog reading to increase photo sensor precission!!
  if (digitalRead(optoPinB) == HIGH) {    // opt sw triggered?
//  if (analogRead(optoPinB) >= 614) {      // opt sw triggered? 60% of 1023
    // ERROR: Photo sensor blocked or defect!
    // Please restart machine or call for assistance!
    while (true) {};    // "STOP"; loop for ever
  }

  // move to reference opt sw in -dir and store position
  // ...
  float dist;
  if (!((TOL_LOW < dist) && (dist < TOL_HIGH))) {
    // ERROR: Measurement area blocked!
    // Remove all parts and press \"Start\"
    return;
  }

  // move to reference opt sw in -dir and store position
  // for a 2nd time (5 mm)
// TODO: tolerance for difference of reference values? compare reference values?
// TODO: Besprechen mit HJ; macht das Sinn?
//   ? - -> wie sollte denn auf Fehler reagiert werden?
  // ...

  // 2 values!
  if (!((TOL_LOW < dist) && (dist < TOL_HIGH))) {
    // ERROR: Optical switch not in tolerance!
    // Initialize again by pressing \"Start\"
    return;
  }

  // zero axis - position tracking
// TODO: how precise is position tracking?
  // ...

  // fast move in +dir to waiting position (~1 mm before mech. sw.)
// TODO: stop closer to dicing blade? (see next step also)
  // ...

// TODO: Besprechen mit HJ; kann je nach waiting position im Schritt vorher gar nicht sein
//   +/- -> Fehler tritt nie auf
//   ? - -> wie sollte denn auf Fehler reagiert werden?
  if (digitalRead(swchPinB) == HIGH) {    // mech sw pressed?
    // ERROR: End switch pressed!
    // Initialize again by pressing \"Start\"
    return;
  }

  oled.clear();
  oled.println("Ready: Place dicing blade");
  oled.println("and press \"Start\"");

// TODO: "DB" with pre-selectable dicing blades (diameter, tolerance during use) from SD card, with multi-switch
}

bool run_measurement() {
  // wait for "Start" button (has pull-up on port)
  while (digitalRead(START_BUTTON) == HIGH) {};

// TODO: Besprechen mit HJ; kann je nach waiting position im Schritt vorher gar nicht sein
//   +/- -> Fehler tritt nie auf
//   ? - -> wie sollte denn auf Fehler reagiert werden?
  if (digitalRead(swchPinB) == HIGH) {    // mech sw pressed?
    // ERROR: End switch pressed!
    // Initialize again by pressing \"Start\"
    return true;
  }

  // move to reference opt sw in -dir and store position
  // do this 3 times - go back in +dir ~3 mm each time
  // ...

  // 3 values!
  float dist;
  if (!((TOL_LOW < dist) && (dist < TOL_HIGH))) {
    // ERROR: Measurement not in tolerance!
    // Reinsert dicing blade and press \"Start\"

    // fast move in +dir to waiting position (~1 mm before mech. sw.)
    // ...

// TODO: Besprechen mit HJ; kann je nach waiting position im Schritt vorher gar nicht sein
//   +/- -> Fehler tritt nie auf
//   ? - -> wie sollte denn auf Fehler reagiert werden?
    if (digitalRead(swchPinB) == HIGH) {    // mech sw pressed?
      // ERROR: End switch pressed!
      // Initialize again by pressing \"Start\"
      return true;
    } else {
      return false;
    }
  }

  // calculate diameter, see drawing
  float diameter;
  // ...

  oled.print("Diameter: ");
  oled.print(diameter);
  oled.println(" mm");
  oled.println("Press \"Start\" for");
  oled.println("the next measurement");

  // fast move in +dir to waiting position (~1 mm before mech. sw.)
  // ...

// TODO: Besprechen mit HJ; kann je nach waiting position im Schritt vorher gar nicht sein
//   +/- -> Fehler tritt nie auf
//   ? - -> wie sollte denn auf Fehler reagiert werden?
  if (digitalRead(swchPinB) == HIGH) {    // mech sw pressed?
    // ERROR: End switch pressed!
    // Initialize again by pressing \"Start\"
    return true;
  } else {
    return false;
  }
}

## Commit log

2018-03-16 first commit of material
2018-03-16 migration; adopted file name to match directory (as requested by Arduino IDE)
2018-03-16 new; CAD (Catia) data files added
    [40 mm Aluprofil v13.f3d, 40 mm Aluprofil v13.iges, 40 mm Aluprofil v13.step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]
2018-03-21 improvement; info and links added * FreeRTOS + stepper motor * Stepper motor libs * PCB Arduino eagle footprint
2018-03-23 improvement; * add datasheets (into new folder) * add part list (docu)
    [Materialliste.xlsx]
2018-03-26 improvement; * added info about OLED Arduino library * added todo for schematic * added todo for mechanics * modified code for testing a bit new feature; * added part list
    [Materialliste.csv, Materialliste.xlsx]
2018-03-28 improvement; * merge/add submodul linear-power-supply https://git-scm.com/book/de/v1/Git-Tools-Submodule
2018-03-28 improvement; * add code for init/setup * add code for self-test * add code and switch for serial (debug) output
    [Materialliste.xlsx]
2018-03-28 * improvement; * added self-test for mechanical switch
2018-03-28 improvement; * travis: use Arduino IDE 1.8.1 for testing * travis show repository directory tree * update docu (consider using inotool)
2018-03-29 follow-up; * bugfix travis inotool test; * try arduino ide 1.8.2 for testing
2018-03-29 follow-up; * disable travis inotool improvement; * use arduino ide 1.8.2 for testing
2018-04-04 improvement; * enhance optical switch (open and close connection) * by that enhance self-test * use laurb9/StepperDriver for now
2018-04-04 improvement; * add pcb image and edrc status (from eagle repo)
2018-04-05 new feature; * add CAD as .stl files in order to use github features
    [40 mm Aluprofil v13.stl]
2018-04-05 improvement; * add CAD stl file link to README
2018-04-05 improvement; * clean-up cad stl file parts
2018-04-05 improvement; * some links for online .stl conversion added to docu
2018-04-05 improvement; * ethz gitlab has .stl viewer too
2018-04-06 improvement; * add missing .stl files * add more verbose status html
    [Saegeblatt_Anschlag.stl, Saegeblatt_Endplatte.stl, Saegeblatt_Schlitten.stl]
2018-04-06 improvement; * add Arduino Uno schematic (e.g. for VIN)
2018-04-06 clean-up; * part list updated
    [Materialliste.csv, Materialliste.xlsx]
2018-04-06 bugfix; * add Arduino SSD1306Ascii library to travis run
2018-04-06 improvement; * init code with OLED support * minimal error handling
    [Blattdurchmesser.ino]
2018-04-06 improvement; * add Hansjakobs flow diagram as pseudo code
2018-04-13 new feature; * add travis eagle integration (gerber)
2018-04-19 improvement; * use correct project name for docu * add Materialliste.htm for docu * change docu formatting back to original (for github)
